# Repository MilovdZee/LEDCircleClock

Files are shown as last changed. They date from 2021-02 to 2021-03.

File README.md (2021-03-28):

# LEDCircleClock
A clock with 241 RGB LEDs.

## Description
The clock shows the hands in diferent colors on the grid of LEDs. To make it more beautiful hands are antialiased. The brightness of the LED is calculated from the distance to the virtual pixel. I also use the milliseconds clock of the Arduino combined with the NTP clock to have a seconds hand that rotates fluently instead of ticking the seconds.

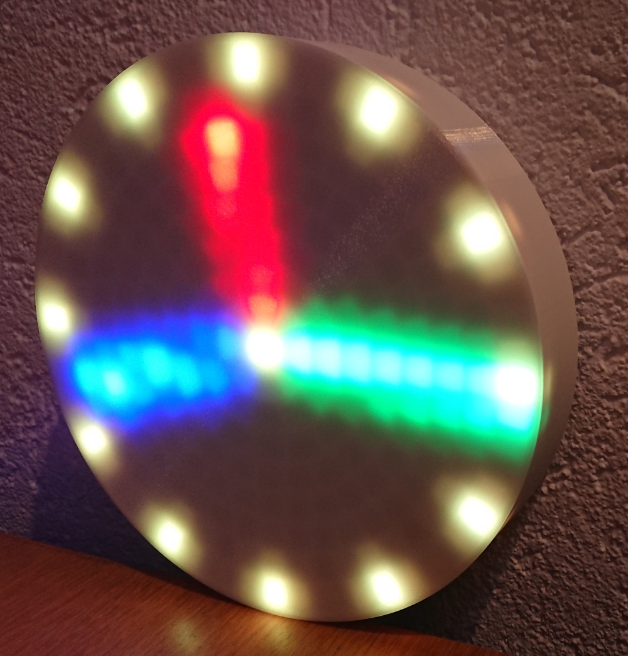
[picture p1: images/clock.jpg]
 

Filming this does not show the colors I see. It looks a lot warmer and more saturated in real life.

## Introduction
As a sucker for clocks I'm always looking for cool projects surrounding clocks. At our favorite Chinese shop I found a 241 LED ring that demanded to become a clock. So I ordered one and waited the standard couple of weeks for it to arrive. Nice, It looked perfect and very easy to use. Data-in and Data-out were next to each other and could simply be daisy-chained with a short piece of wire. Effectively the ring became a strand of 241 LED's all addressable from a serial bus.

Now I needed to design a enclosure. Each LED needs to be separate from the neighboring LEDs. Some calculations were needed but after a couple of hours I had my 3D design in Blender. 26 hours of printing resulted in an enclosure that perfectly fits the LED ring.

I started by testing with an example program to see if all functions as expected and it did. The current it takes at full brightness is a bit high but that is no problem while the clock in normal operation is not at full brightness and not all LEDs are lit.

After the testing I wrote an Arduino program to show time based on NTP and once in a while shows an effect.

Some trickery was needed. I wanted the seconds hand to move smoothly and so I used the milliseconds as an offset to the seconds. 

Calculating the hands uses the 'pow()' function and that is a very CPU intensive operation. That is why I created a function that caches the previous values of the 'pow()' function to make it a lot faster.

After all I'm quite happy with the result :)

## Effects
At random moments the clock is replaced by an effect. Just for a couple of seconds.

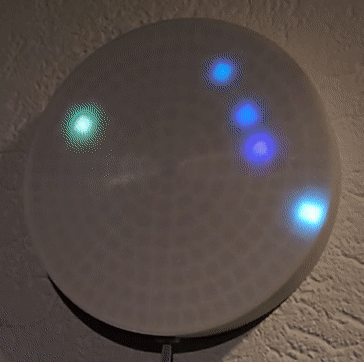
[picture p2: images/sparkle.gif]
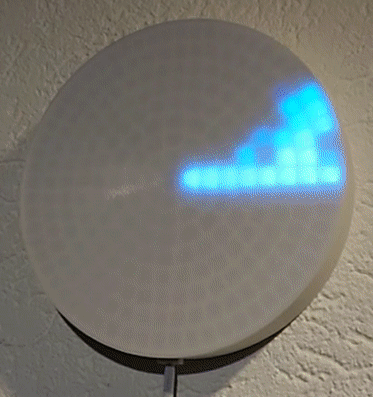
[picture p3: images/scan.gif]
  

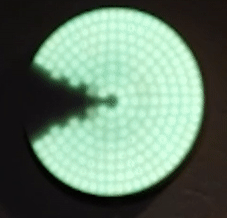
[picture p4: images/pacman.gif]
 

# Hardware
- esp8266 / NodeMCU
- DC-DC converter if you like to accept multiple input voltages. The LED ring contains 241 LEDs and can consume up to 3.5 Amps. An XL4015 version sound like capable of handling this.
- LED ring. Search aliexpress for "241 led ring". The diameter is 170mm.

## Schematics
Not really schematics but more like a wiring diagram. The schematics are not even worth drawing out :)

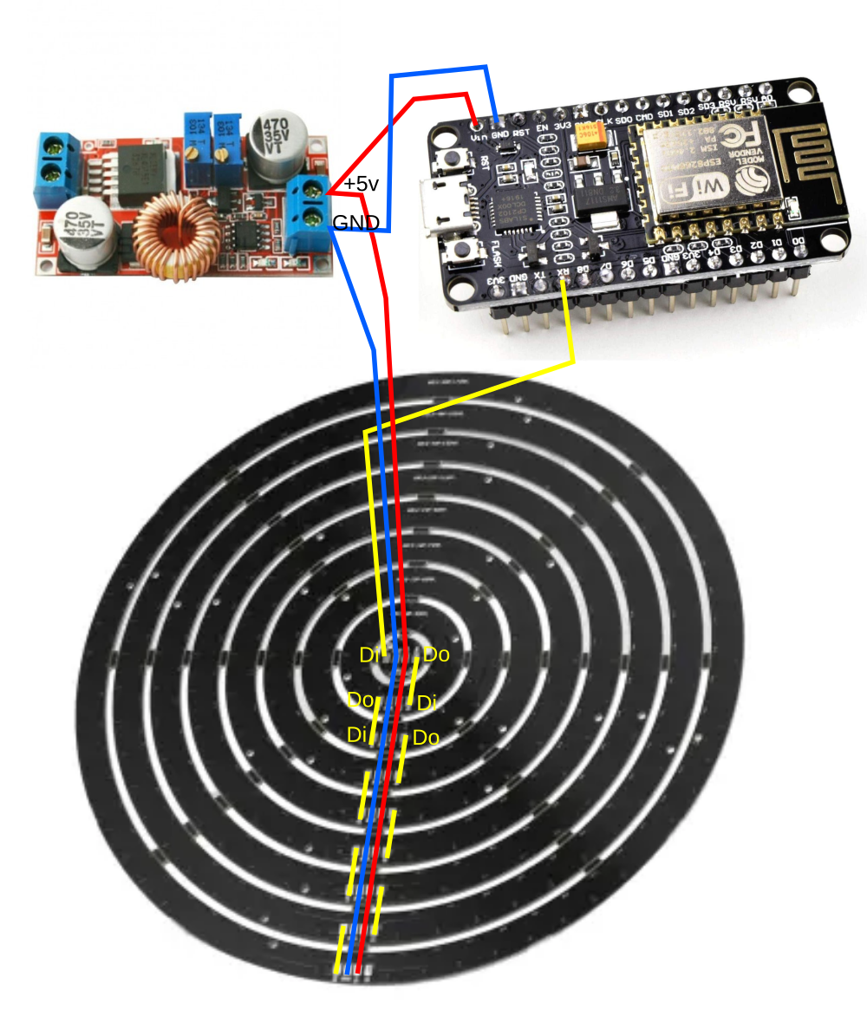
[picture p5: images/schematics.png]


## 3D printed Case
I designed the case in Blender and the files can be found in this project. Together with the STL files.
The STL for the front with dividers is in one STL file. Make sure to split it in two materials. One semi transparent first 2mm and the rest an opaque color. Also make sure to print the front first layer in a spiral. This removed the step of the print head to the next ring.

The cable hole was a bit of an afterthought. Originally it was intended to have an USB-C power supply but that ended up being more complicated than benneficial. Still, if you like to use USB-C then you could use the design and expose the USB-C connector.

I printed the case in PETG because this seems to be the only type that has transaparent filament. It took about 26 hours for the grid and front panel and another 5 hours for the back. Electronics holder and cable hole were much quicker.
I like to print in .15 mm resolution so this is also a reason why it took that long.

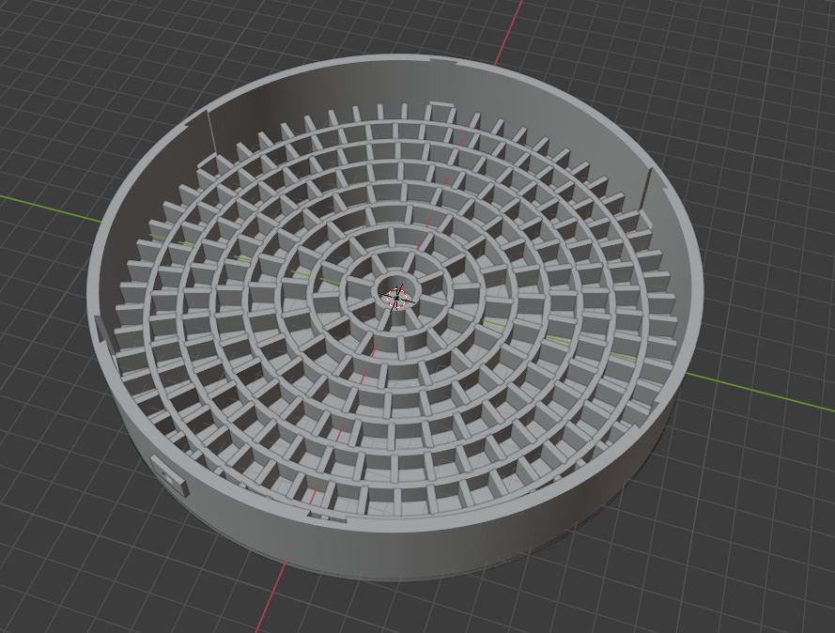
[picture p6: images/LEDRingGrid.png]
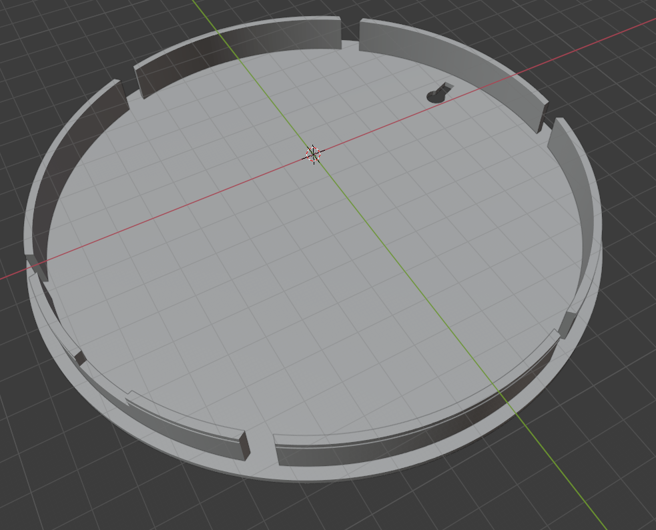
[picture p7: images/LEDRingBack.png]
 
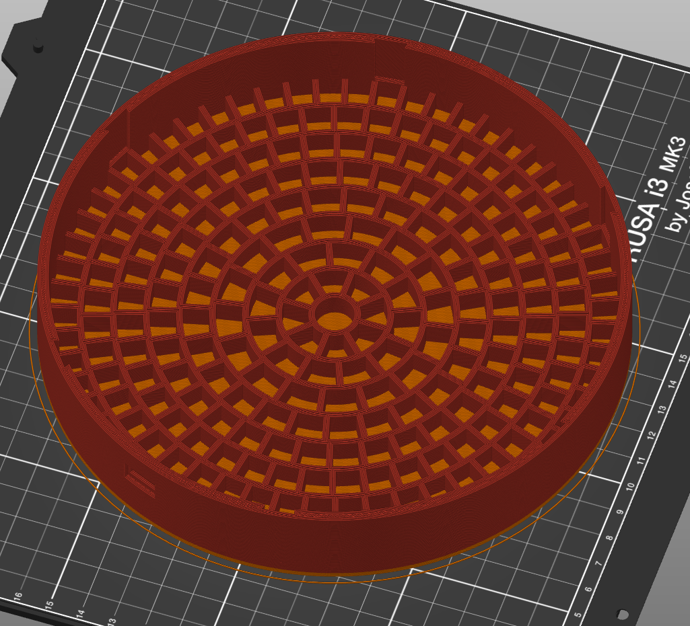
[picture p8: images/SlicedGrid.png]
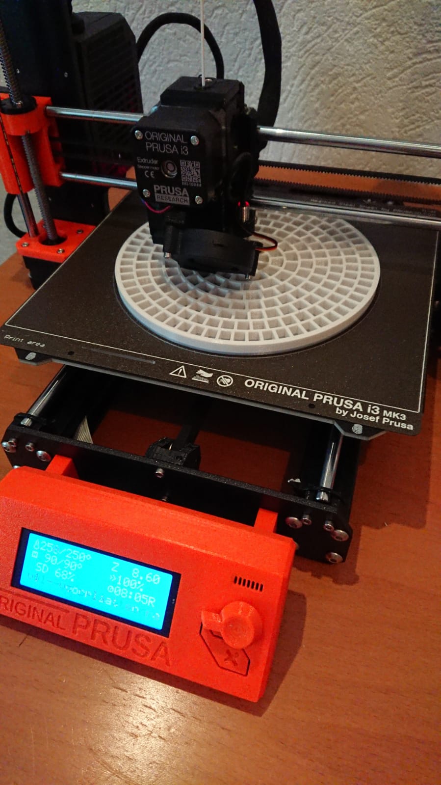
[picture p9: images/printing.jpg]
 
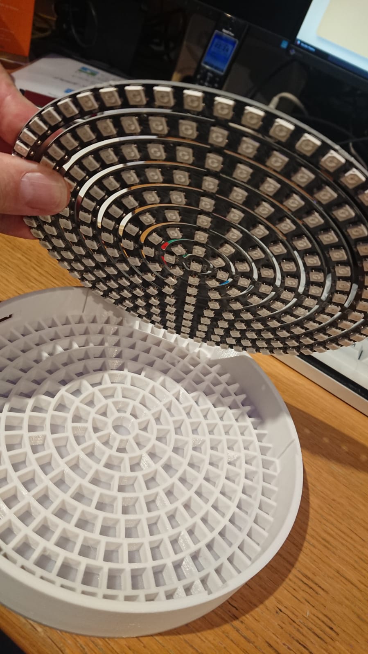
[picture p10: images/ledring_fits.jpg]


## LED ring
As mentioned, just search for "241 LED ring". The prices varies a lot so make sure to compare them. Mine was about €17,-.

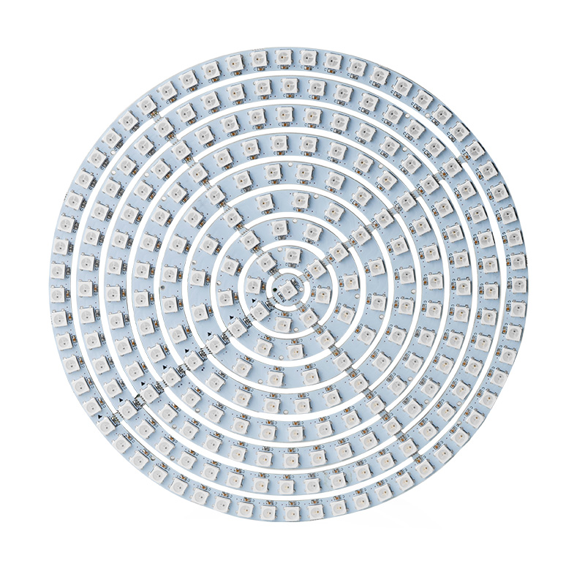
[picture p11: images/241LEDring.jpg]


# Software
The software is written for the Arduino IDE. 
- NTP to synchronize the time
- OTA for wireless code updates. The OTA password as set in this repo is 'KlokPassword'.
- WEB interface to configure brightness and WIFI settings. The ip address is received through DHCP and so should be looked up in the router. Or use the Arduino IDE to find it. It will show up as a port after restarting the IDE.
- If WIFI is not found the esp8266 becomes an open access point. Pointing a browser to http://192.168.4.1/wifi opens the WIFI configuration page.
- At random moments an effect is shown (sparkle, pacman, scan, fire)

## Libraries
- NeoPixelBus by Makuna
- NTPClient

The libraries can be installed under "Sketch -> Include Library -> Manage Libraries..."

And additional board manager for the ESP8266: http://arduino.esp8266.com/stable/package_esp8266com_index.json. This must be set under "File->Preferences->Additional Boards Manager URLs".

## Change Log

- March 21, 2021: Use native ESP NTP timekeeping, instead of external NTP library, and make it use automatic summer/winter time switch (Thijs Kaper)

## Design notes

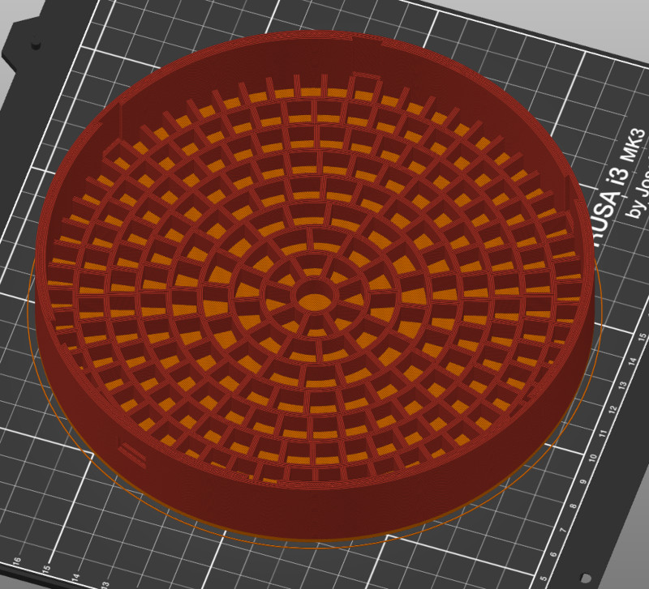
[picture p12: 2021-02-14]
images/Smaller versions/SlicedGrid.jpg

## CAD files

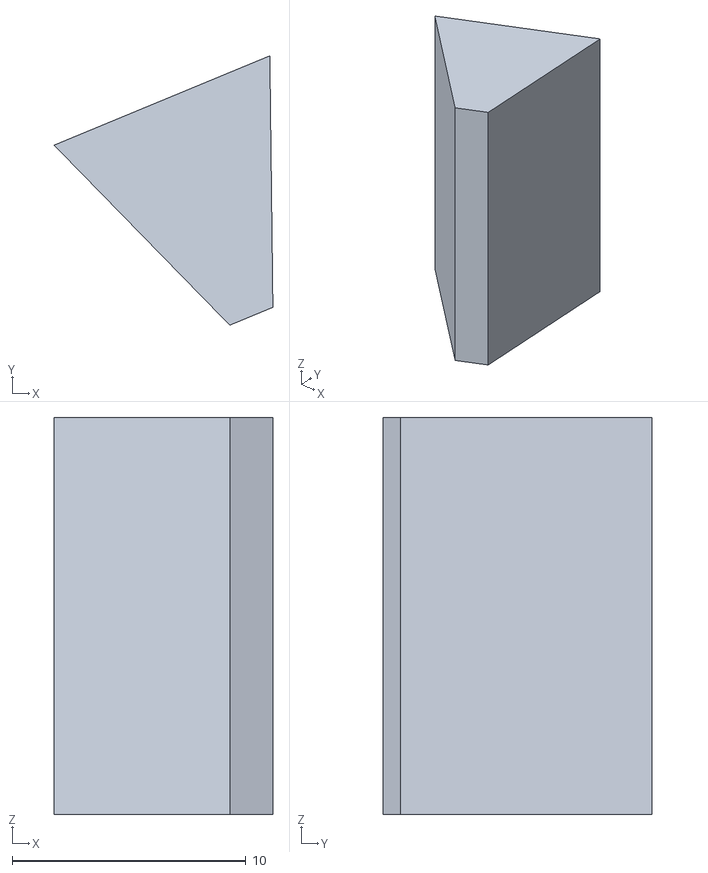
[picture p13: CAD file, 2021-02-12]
Blender/LED ring v1 - schuifblokje.stl
9.37 x 11.5 x 17.0

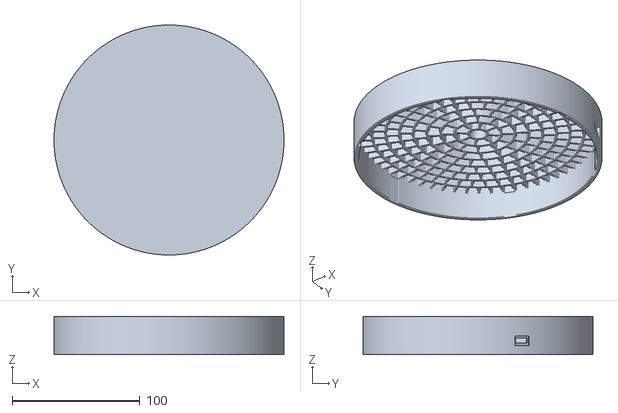
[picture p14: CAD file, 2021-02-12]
Blender/LED ring v1 - voorplaat en raster.stl
180.0 x 180.0 x 30.0

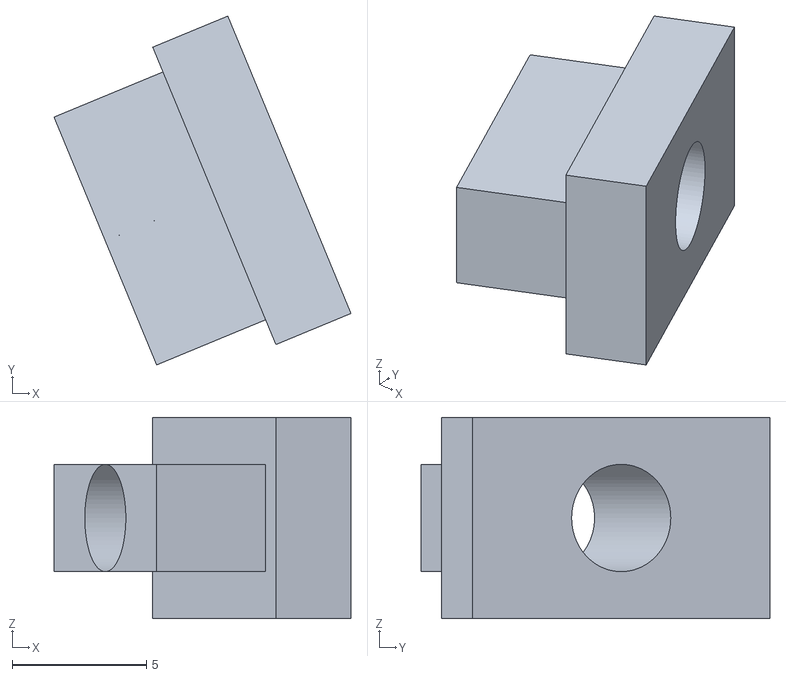
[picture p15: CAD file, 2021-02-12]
Blender/LED ring v1 - kabelgeleider.stl
11.1 x 13.0 x 7.50

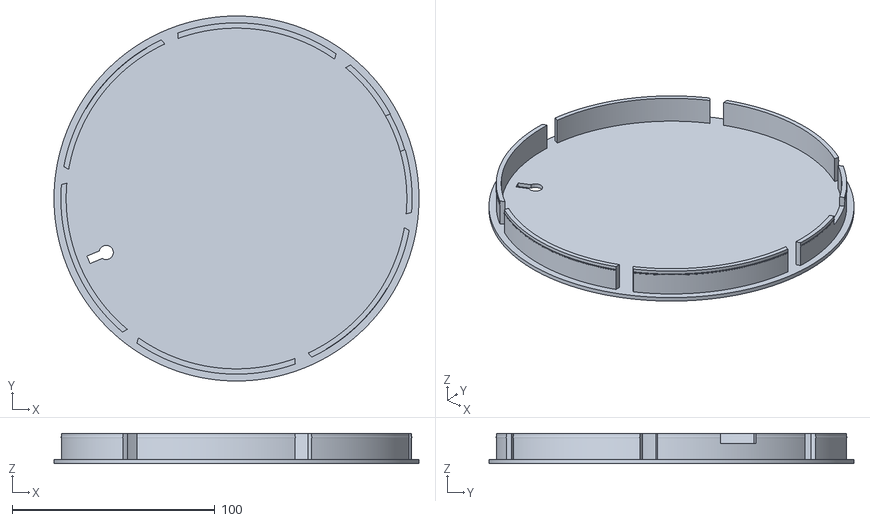
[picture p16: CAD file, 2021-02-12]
Blender/LED ring v1 - achterkant.stl
180.0 x 180.0 x 15.0

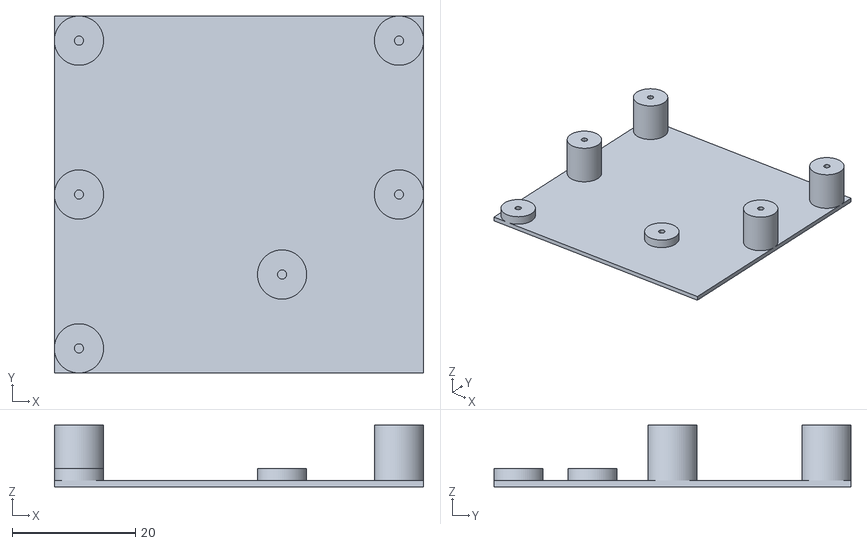
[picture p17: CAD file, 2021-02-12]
Blender/LED ring v1 - elektronica.stl
60.0 x 58.0 x 10.0

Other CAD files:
Blender/LED ring v1.blend

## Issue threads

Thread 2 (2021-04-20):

Cannot connect to wifi lan

jdhysell, 2021-04-20:
I run several wifi lan segments. A couple are open with no password, and others are password protected. I can connect to the ESP8266 while it is in access point mode, and configure the wifi setup to point to the wifi lans, but upon reboot, the ESP8266 attempts to connect and fails - all segments fail - with or with no password protection.  (Attempts are visible in the serial output session) Am I missing something here? Thanks for any help. Really looking forward to getting this clock running. 3D prints are done - just waiting for the programming...

MilovdZee, 2021-04-20:
Are any of the access points you tried in the 2.4GHz band? I also noticed that some access points have WPA3 and I think the ESP only supports WPA. Not even WPA2. But I'm not sure.

I checked the setup by enabling the hotspot on my phone and that worked.

jdhysell, 2021-04-20:
Yes. All access points support 2.4 GHz.I don't have WPA engaged. I can set one AP to use WPA and test that.
thanks for the suggestion.-John
    On Tuesday, April 20, 2021, 02:49:49 PM EDT, MilovdZee ***@***.***> wrote:

Are any of the access points you tried in the 2.4GHz band? I also noticed that some access points have WPA3 and I think the ESP only supports WPA. Not even WPA2. But I'm not sure.

I checked the setup by enabling the hotspot on my phone and that worked.

—
You are receiving this because you authored the thread.
Reply to this email directly, view it on GitHub, or unsubscribe.

MilovdZee, 2021-04-20:
And open access point probably don't work with the current code. The sketch just always sends the username and password. Please let me know if you get it to work. Else I can try to allow for open access points.

MilovdZee, 2021-04-20:
And nice that you are building one. I'm enjoying mine very much :)

jdhysell, 2021-04-20:
I live in a very rural area in central New York. (Nearest neighbor is 1/4 mile away...)
So AP security is not high on my priority listRunning open AP's makes connectivity fast and simple
8-)

    On Tuesday, April 20, 2021, 03:00:46 PM EDT, MilovdZee ***@***.***> wrote:

And open access point probably don't work with the current code. The sketch just always sends the username and password. Please let me know if you get it to work. Else I can try to allow for open access points.

—
You are receiving this because you authored the thread.
Reply to this email directly, view it on GitHub, or unsubscribe.

jdhysell, 2021-04-20:
hmmmno joy using an AP running WPA
see serial output below:-----------------------------------------------------onnecting to WIFI 'store'...Connection Failed! Continuing...IP address: (IP unset)
Running...
----------------------------------------------------
AP settings:

    On Tuesday, April 20, 2021, 03:00:46 PM EDT, MilovdZee ***@***.***> wrote:

And open access point probably don't work with the current code. The sketch just always sends the username and password. Please let me know if you get it to work. Else I can try to allow for open access points.

—
You are receiving this because you authored the thread.
Reply to this email directly, view it on GitHub, or unsubscribe.

MilovdZee, 2021-04-21:
Weird. And when you use your phone as access point?
And maybe try with a different ESP? Although this would be unexpected because you say that connecting to it when it is in access point mode is fine.

MilovdZee, 2021-04-21:
You could also try your open networks by changing one line of code:
replace:
`WiFi.begin(String(ssid), String(wifiPassword));`
with
`WiFi.begin(String(ssid));`

jdhysell, 2021-04-21:
not an option - my cell phone plan has no data included.(OK - I am cheap...)
I will modify the WIFI code as you suggest and try again.
I may also try moving closer to the AP.It could be a range limitation on the ESP8266.When I connect to it, my laptop is right next to it.
thx again for your support.-John
    On Wednesday, April 21, 2021, 02:51:30 AM EDT, MilovdZee ***@***.***> wrote:

Weird. And when you use your phone as access point?
And maybe try with a different ESP? Although this would be unexpected because you say that connecting to it when it is in access point mode is fine.

—
You are receiving this because you authored the thread.
Reply to this email directly, view it on GitHub, or unsubscribe.

MilovdZee, 2021-04-21:
No worries. We will get this to work.

jdhysell, 2021-04-21:
The ESP is new out of the box. If I get no joy after a few morechanges, I may get another - possible DOA.
-J
    On Wednesday, April 21, 2021, 06:39:40 AM EDT, MilovdZee ***@***.***> wrote:

No worries. We will get this to work.

—
You are receiving this because you authored the thread.
Reply to this email directly, view it on GitHub, or unsubscribe.

jdhysell, 2021-04-22:
Removing the Password string worked.
NTP gets updated after WiFi connect now.
thanks very much for your help.
(Now time to wire the LED array...)

Connecting to WIFI 'LIVING_ROOM'...Connected to WIFI...IP address: 10.1.254.246
Running...NTP Updated: Thu Apr 22 20:07:56 2021

    On Wednesday, April 21, 2021, 02:55:45 AM EDT, MilovdZee ***@***.***> wrote:

You could also try your open networks by changing one line of code:
replace:
WiFi.begin(String(ssid), String(wifiPassword));
with
WiFi.begin(String(ssid));

—
You are receiving this because you authored the thread.
Reply to this email directly, view it on GitHub, or unsubscribe.

MilovdZee, 2021-05-23:
Probable WPA3 issue. But workaround works

Closed 2021-05-23.

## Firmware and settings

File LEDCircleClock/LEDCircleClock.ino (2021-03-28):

#include <NeoPixelBus.h>
#include <ArduinoOTA.h>
#include <ESP8266WebServer.h>
#include <ESP8266HTTPUpdateServer.h>
#include <EEPROM.h>
#include <TZ.h>
#include <coredecls.h> // required for settimeofday_cb() (NTP sync callback)

#include "defines.h"

boolean timeIsSet = false;
time_t lastNtpSet = 0;
time_t currentTime = time(nullptr); // time_t = seconds since epoch
struct tm * timeinfo;
time_t previousEffectTime = time(nullptr);

int previousClockSecond = -1;
int millisOffset = 0; // Offset compared to millis() to get partial seconds in sync with the NTP seconds

char ssid[60];
char wifiPassword[60];

// Number of rings
#define RINGS 9

// Number of LEDs per ring
int ringSizes[] = {1, 8, 12, 16, 24, 32, 40, 48, 60};

// The higher the power the narrower the region that lights up
int ringPowers[] = {10, 20, 30, 40, 50, 60, 70, 80, 90};

// First LED number of a ring
int startLEDs[RINGS];
int totalLEDs;

const int PIXEL_COUNT = 241; // make sure to set this to the number of pixels in your strip
int brightness; // Brightness between 0 and 255

// For Esp8266, the Pin is omitted and it uses GPIO3(Rx) due to DMA hardware use.
NeoPixelBus<NeoGrbFeature, Neo800KbpsMethod> strip(PIXEL_COUNT);

ESP8266WebServer server(80);
ESP8266HTTPUpdateServer httpUpdater;

// Record the NPT set time
void timeUpdated() {
  timeIsSet = true;
  lastNtpSet = time(nullptr);
  Serial.print("NTP Updated: "); Serial.println(ctime(&lastNtpSet));
}

// Check if NTPD sync was more than ONE hour and 20 SECONDS ago. If so, we show it on screen to indicate we are not sure about the time yet or anymore.
boolean isNtpOlderThanOneHour() {
  // time(nullptr) = time in seconds
  return (!timeIsSet) || (time(nullptr) - lastNtpSet) > 3620;
}

void clearStrip() {
  strip.ClearTo(RgbColor(0, 0, 0));
  strip.Show();
}

void handlingDelay(int delayMillis) {
  ArduinoOTA.handle();
  server.handleClient();

  // Make sure the software watchdog does not trigger
  ESP.wdtFeed();

  if (delayMillis > 0) delay(delayMillis);
}

void setPixel(int pixelNumber, RgbColor color) {
  int red = min((int)color.R, MAX_BRIGHTNESS);
  int green = min((int)color.G, MAX_BRIGHTNESS);
  int blue = min((int)color.B, MAX_BRIGHTNESS);
  RgbColor limitedColor = RgbColor(red, green, blue);
  strip.SetPixelColor(pixelNumber, limitedColor);
}

void setRandomSeed() {
  uint32_t seed;

  // random works best with a seed that can use 31 bits
  // analogRead on a unconnected pin tends toward less than four bits
  seed = analogRead(0);
  delay(1);

  for (int shifts = 3; shifts < 31; shifts += 3) {
    seed ^= analogRead(0) << shifts;
    delay(1);
  }

  // Serial.println(seed);
  randomSeed(seed);
}

void setup() {
  Serial.begin(115200);
  while (!Serial); // wait for serial attach

  // For the ESP the flash has to be read to a buffer
  EEPROM.begin(512);

  strip.Begin();
  strip.Show();

  // Setup the wifi
  EEPROM.get(SSID_ADDR, ssid);
  EEPROM.get(WIFI_PASSWORD_ADDR, wifiPassword);
  Serial.print("\r\nConnecting to WIFI '");
  Serial.print(String(ssid));
  Serial.print("'...\r\n");
  strip.SetPixelColor(0, RgbColor(0, 0, 50));
  strip.Show();
  WiFi.mode(WIFI_STA);
  WiFi.hostname(HOSTNAME);
  WiFi.begin(String(ssid), String(wifiPassword));
  if (WiFi.waitForConnectResult() != WL_CONNECTED) {
    Serial.println("Connection Failed! Continuing...");
    strip.SetPixelColor(0, RgbColor(50, 0, 0));
    strip.Show();
    WiFi.mode(WIFI_AP);
    WiFi.softAP(HOSTNAME);
  } else {
    Serial.println("Connected to WIFI...");
    strip.SetPixelColor(0, RgbColor(0, 50, 0));
    strip.Show();
  }
  Serial.print("IP address: ");
  Serial.println(WiFi.localIP());
  delay(1000);

  // implement NTP update of timekeeping (with automatic hourly updates)
  configTime(MY_TZ, NTP_SERVERS);

  // callback, when NTP changes the time
  settimeofday_cb(timeUpdated);

  setupOTA();

  EEPROM.get(BRIGHTNESS_ADDR, brightness);

  // Setup the web server
  httpUpdater.setup(&server);
  server.on("/", handleRoot);
  server.on("/wifi", handleWifi);
  server.begin();

  clearStrip();

  // Set the start LED numbers for every ring
  int startLED = 0;
  for (int ring = 0; ring < RINGS; ring++) {
    startLEDs[ring] = startLED;
    startLED += ringSizes[ring];
  }
  totalLEDs = startLED + ringSizes[RINGS - 1];

  setRandomSeed();

  Serial.println();
  Serial.println("Running...");
}

void executeEffect(int choice) {
  switch (choice) {
    case 0:
      sparkle();
      break;
    case 1:
      pacman();
      break;
    case 2:
      scan();
      break;
    case 3:
      fire();
      break;
  }
}

int count = 0;
void loop() {
  currentTime = time(nullptr); // time_t = seconds since epoch
  timeinfo = localtime (&currentTime); // setup timeinfo -> tm_hour, timeinfo -> tm_min, timeinfo -> tm_sec

  if (previousEffectTime != currentTime) {
    previousEffectTime = currentTime;
    if (random(30) == 0) {
      int effectChoice = random(4);
      executeEffect(effectChoice);
    }
  }

  ArduinoOTA.handle();
  server.handleClient();

  updateClockHands();
}

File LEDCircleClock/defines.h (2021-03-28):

#define PASSWORD "KlokPassword"
#define HOSTNAME "LED-Klok"

#define SSID_ADDR 0 // String[60]
#define WIFI_PASSWORD_ADDR (SSID_ADDR + sizeof(ssid)) // String[60]
#define BRIGHTNESS_ADDR (WIFI_PASSWORD_ADDR + sizeof(wifiPassword)) // int

// Limit the power consumption. A full lit display can take up to 4 Amps.
// A value of 255 disabled the limit and allows all LEDs to be full brightness.
#define MAX_BRIGHTNESS 100

// The timezone to sync the date/time to, using NTP. For timezone to use, see TZ.h.
#define MY_TZ TZ_Europe_Amsterdam

// NTP server list to use for syncing time.
#define NTP_SERVERS "0.nl.pool.ntp.org", "1.nl.pool.ntp.org", "2.nl.pool.ntp.org"

#define CSS "<style>\
  body {\
    background: #fad7a0;\
    color: #154360;\
    padding: 20px;\
    font-size: 3em;\
    text-align: center;\
  }\
  div.container {\
    display: inline-block;\
    width: 90%;\
    height: 90%;\
    background: #f8c471;\
    box-shadow: 15px 20px 20px #88888888;\
    border-radius: 20px;\
    padding: 2%;\
    text-align: left;\
  }\
  h1 {\
    margin-top: 0;\
  }\
  input {\
    width: 100%;\
    border: 0;\
    border-bottom: 2px solid grey;\
    background: none;\
    color: #154360;\
    font-size: 1.2em;\
  }\
  input[type=\"range\"] {\
    width: 100%;\
  }\
  input[type=\"submit\"] {\
    background: #154360;\
    color: #fad7a0;\
    border: 0;\
    border-radius: 5px;\
    width: 40%;\
    height: 10%;\
    cursor: pointer;\
    font-size: 1em;\
    position: absolute;\
    left: 30%;\
    bottom: 20%;\
  }\
  div div {\
    position: absolute;\
    right: 2%;\
    bottom: 2%;\
    font-size: .6em;\
  }\
</style>"

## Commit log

2021-02-12 fix arduino layout of files
    [LEDCircleClock.ino, clock.ino, defines.h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]
2021-02-12 added Blender files
    [LED ring v1 - achterkant.stl, LED ring v1 - elektronica.stl, LED ring v1 - kabelgeleider.stl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]
2021-02-12 add LED ring image
2021-02-12 add schematics
2021-02-13 update schematics
